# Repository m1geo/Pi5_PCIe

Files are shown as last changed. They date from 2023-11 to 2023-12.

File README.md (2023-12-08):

# Pi5 PCIe & M2 NVMe
A crude reverse engineering of the Raspberry Pi 5's FPC PCIe connector &amp; potential breakout board.

OFFICIAL RASPBERRY PI PCIE DOCOUMENTATION CAN BE FOUND HERE: https://datasheets.raspberrypi.com/pcie/pcie-connector-standard.pdf

In this bare-bones project I document a working PCIe pinout talk through my hardware tinkering to get the Raspberry Pi 5's PCIe connected to something. I had only seen Raspberry Pi's boards with their RP2040 and lots of parts on board. My professional experience with PCIe was that it either just goes or it really doesn't. I decided to try and make it do something for no reason other than the technical challenge.

To see what I did, check out my walkthrough of the process on YouTube: [Raspberry Pi 5 - Unofficial PCIe Success - Hacking the Pi5's PCIe into life](https://youtu.be/G5VOzO_ERTM).

**Note: This project is a reverse engineering - Please wait for/use the [official Raspberry Pi PCIe documentation](https://datasheets.raspberrypi.com/pcie/pcie-connector-standard.pdf) when using the PCIe FPC**

## Pi5 PCIe Breakout Board

The board is a quick test board. It could definitely be improved :)

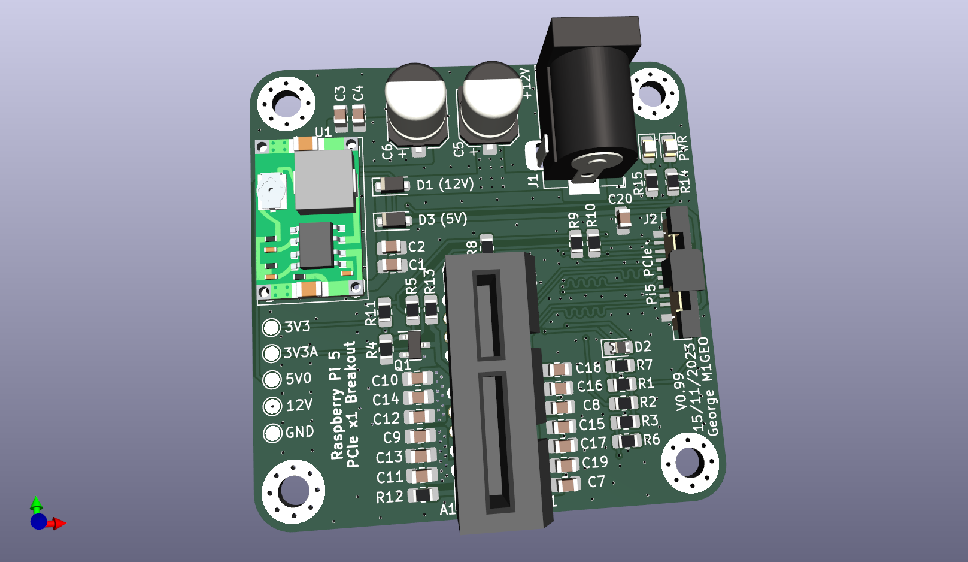
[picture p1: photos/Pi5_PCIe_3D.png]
3D Model of PCIe board


## Pi5 M.2 NVMe Breakout Board

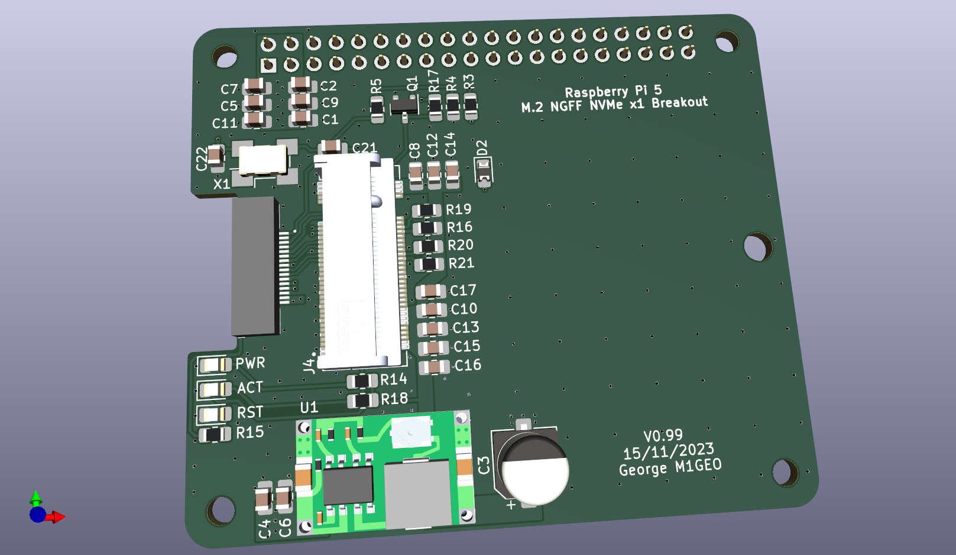
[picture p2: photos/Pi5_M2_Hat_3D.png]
3D Model of M.2 NVMe board


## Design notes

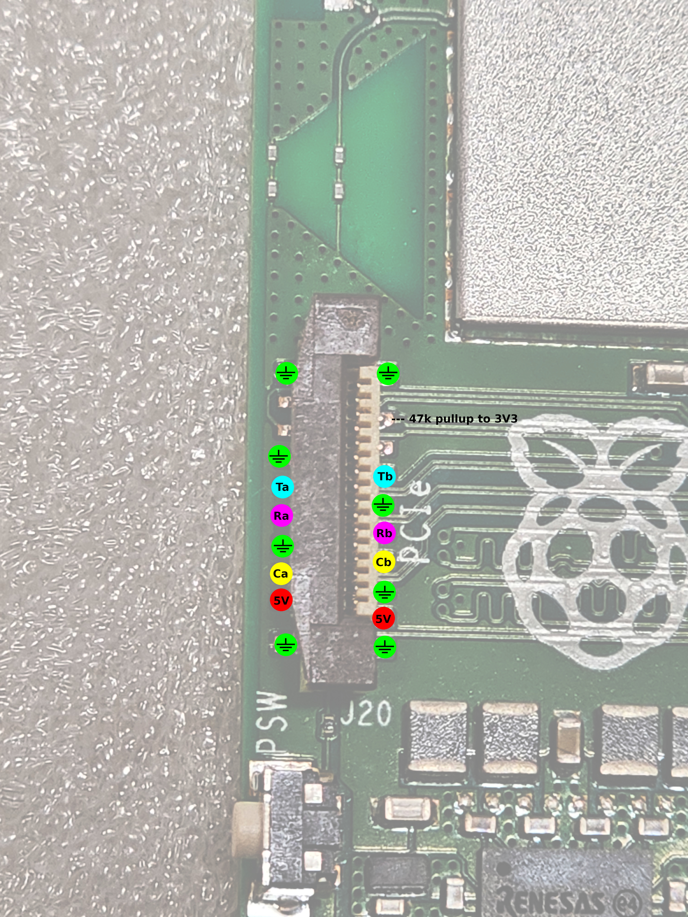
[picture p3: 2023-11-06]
photos/pinout_m1geo.jpg

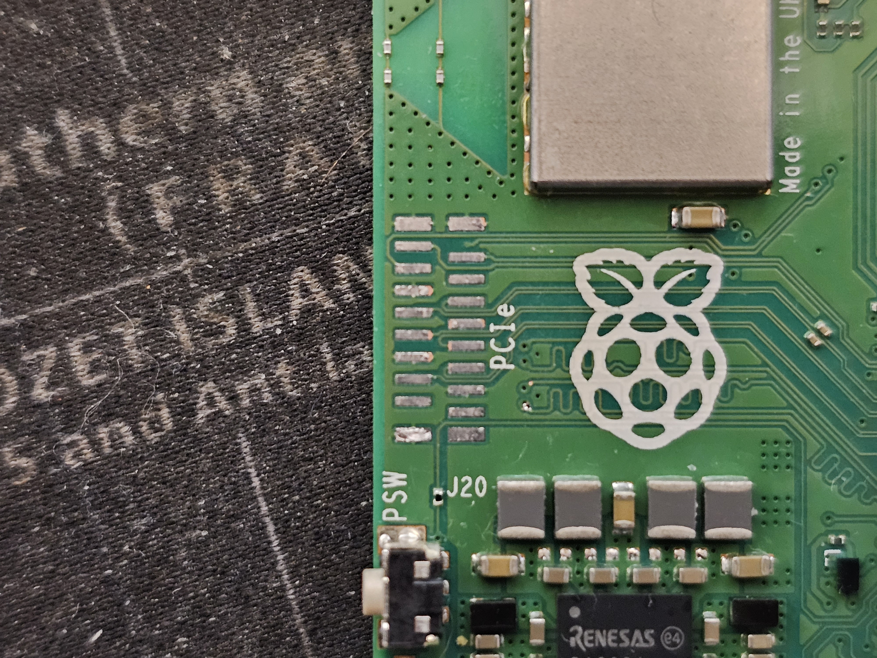
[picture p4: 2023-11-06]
photos/pinout_m1geo2.jpg

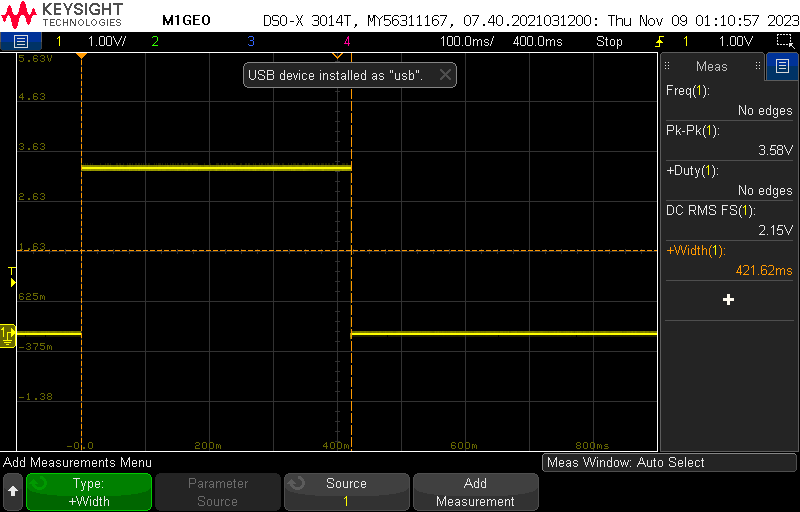
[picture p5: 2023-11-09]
photos/scope_1_pcie_pin1_highpulse.png

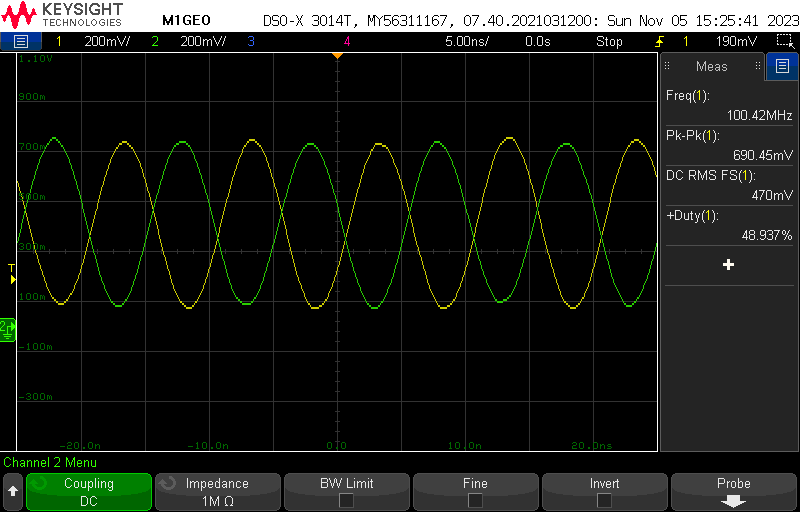
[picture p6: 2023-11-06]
photos/scope_0_pcie_refclk.png

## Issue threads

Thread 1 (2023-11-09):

I2C

trejan, 2023-11-09:
I suspect P3+P4 are I2C and used to communicate with the RP2040 seen on the prototype M.2 HAT. The BCM2712 has two pins muxed to the I2C peripheral and they're named PCIE_SCL/SDA. It isn't the RP1 either as that has a separate I2C bus.

These two pins are configured with the weak internal pulldown enabled and always read as low. The M.2 HAT presumably has the missing I2C pullup resistors.

```
114: a1    pd | lo // PCIE_SDA/GPIO14 = SPI_S_MOSI_OR_BSC_S_SDA
115: a1    pd | lo // PCIE_SCL/GPIO15 = SPI_S_SCK_OR_BSC_S_SCL
```

Should be easy enough to confirm by running _pinctrl_ before & after pulling the pins high.

m1geo, 2023-11-09:
Thanks for this. I'll add provision for this on the board. That's really useful knowledge. I'm also pretty sure that P1 is RST and P2 is CLKREQ (based on probing around with the scope some more). Means there is likely no presence detect (or some magic the RP2040 is doing over I2C with the driver?).

trejan, 2023-11-09:
I expect autodetection would be via I2C like the Poe HATs. The prototype M.2 HAT has a fan connector and current sensing so that'll be via I2C as well if it ends up in the release board. I don't know how much of this is implemented in the public firmware though.

Adding a couple pullup resistors might make it show some activity during startup.

m1geo, 2023-11-09:
Will give that a shot. I'm just looking at the kernel & DT overlay source on the Pi5 GitHub. See if I can work out a way to tell SCL vs SDA when there's no data/clock on the bus.

trejan, 2023-11-09:
Pull up only 1 and see what changes in pinctrl?

m1geo, 2023-11-09:
Using [pinctrl](https://github.com/raspberrypi/utils/tree/master/pinctrl) as suggested by @trejan the following can be observed:

```
$ diff idle.txt p3_high.txt
< 114: a1    pd | lo // PCIE_SDA/GPIO14 = SPI_S_MOSI_OR_BSC_S_SDA
> 114: a1    pd | hi // PCIE_SDA/GPIO14 = SPI_S_MOSI_OR_BSC_S_SDA
```

```
$ diff idle.txt p4_high.txt
< 28: no    pd | lo // PCIE_RP1_WAKE/GPIO28 = none
> 28: no    pd | hi // PCIE_RP1_WAKE/GPIO28 = none
< 115: a1    pd | lo // PCIE_SCL/GPIO15 = SPI_S_SCK_OR_BSC_S_SCL
> 115: a1    pd | hi // PCIE_SCL/GPIO15 = SPI_S_SCK_OR_BSC_S_SCL
```

Interesting that the PCIE_WAKE signal appears to be trigged with the clock being high. Taking this literally, a low BSC_S_SCL/GPIO15 indicates the PCIE_nWAKE request, too? Perhaps the signalling is to use the I2C clock stretching condition to signal a wake?

Couldn't get any life out of P1 and P2. Grounding P2 resulted in no difference from _pinctrl_. I was hoping it may have triggered `RP1_PCIE_CLKREQ_N` (as below) but nothing. Most likely this is for the RP1 chip as RP1 is in the name.

> 36: no    pd | lo // RP1_PCIE_CLKREQ_N/GPIO36 = none

Closing ticket. I2C pins identified. Thanks for the help @trejan!

m1geo, 2023-12-08:
Looking at the [official Pi5 PCIe documentation](https://datasheets.raspberrypi.com/pcie/pcie-connector-standard.pdf),

P4=PCIE_SCL and WAKE is correct.
P3=PCIE_SDA also appears to serve as a PWR_EN signal.

Closed 2023-11-09.

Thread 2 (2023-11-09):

PCIe Lane inter-pair reversal

m1geo, 2023-11-09:
The prototype M.2 HAT doesn't appear to have crossed PCIE_RX0P/N pairs, so I suspect I have them around the wrong way. It works on hardware both ways, so at least one end autodetects. Thus, can't rely on the "working" to be the indicator, and now using the PCB traces to inform.

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
[_AltText:_ Quick drawing showing the RX pair lanes are swapped on the Pi5 connector, confirming there is no twist on the M.2 hat]

Closed 2023-11-09.

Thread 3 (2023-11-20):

help wanted: what is the purpose of optional block?

ubopod, 2023-11-20:
I was wondering what is the purpose of this optional block (oscillator):

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

I guess it would be possible to get full power via FPC connector and connection to Raspberry Pi header 5v is optional?

mfolejewski, 2023-11-22:
that's SUSCLK (32kHz)

"SUSCLK is a 32 kHz clock useful for card power-saving but not required in practice"

https://hackaday.com/2022/11/03/m-2-for-hackers-connectors/

m1geo, 2023-11-23:
Correct. It is to allow peripheral devices to operate from a slow, low power clock in order to do things like assert PCIE_WAKE#. Useful for things like wake-on-LAN.

Closed 2023-11-23.

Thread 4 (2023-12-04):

Hat ID EEPROM

mariusmotea, 2023-12-04:
Hi,

I notice you connect the i2c pins to SMDAT and SMCLK but i think most likely these must be connected to an i2c eeprom chip.

https://hackaday.io/project/167888-not-quite-useless-raspberry-pi-replacement/log/170018-raspberry-pi-hat-id-eeprom-details

https://github.com/raspberrypi/hats

```
A board can only be called a HAT if:

It conforms to the basic add-on board requirements
It has a valid ID EEPROM (including vendor info, GPIO map and valid device tree information).
```

m1geo, 2023-12-07:
The HAT ID EEPROM (including vendor info, GPIO map and valid device tree information) is connected to [GPIO1 pin28](https://pinout.xyz/pinout/pin28_gpio1/) and [GPIO0 pin27](https://pinout.xyz/pinout/pin27_gpio0/).

The PCIe_SMDAT and PCIe_SMCLK come via the 16pin FPC cable. they are different I2C controllers. They're likely used for [IPMI based activities](https://en.wikipedia.org/wiki/Intelligent_Platform_Management_Interface) and [SMBus](https://en.wikipedia.org/wiki/System_Management_Bus) and side-channel data.

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

**TLDR: There are many different I2C controllers on the Pi. We're talking about different ones. Hope that helps.**

m1geo, 2023-12-09:
No, I didn't, but the 16p header isn't for the HAT EEPROM. The official spec (see main readme) doesn't list the I2C, so I guess there's no offical support. The HAT EEPROM will need to connect to the GPIO header EEPROM pins.

mariusmotea, 2023-12-09:
Pineberry has released two pcie adapters one using the 40 pin header and one using only the PCIe 16 pin connector. I looked at the pics on the one that use only the PCIe connector and the i2c pins go to two components, one looks to be the eeprom chip and the second is an i2c current measurement.

From specs:

 - Dedicated I2C EEPROM Memory: Fully compatible with HAT ID for advanced functionality and configuration.
 - Advanced Power Monitoring and Diagnostics: Continuous, real-time monitoring and diagnostic system for voltage, current, and power parameters via an I2C interface.

mikegapinski, 2023-12-10:
I can't say too much about this yet but we are planning on using the I2C on the HatDrive Bottom that does not use the GPIO directly. The current monitoring feature is very important to us and we found a decently elegant solution that will make it work without any hardware changes on the boards that are currently shipping out.

We do however ship both the boards in the first batch with an empty EEPROM since the payload for auto detection is not yet public, we'll release an update script that'll make it work as soon as we know the details. Right now you need to use the PCIE_PROBE bootloader config flag to enable booting from NVMe. That is what the HAT+ spec will bring.

I don't understand why:
1. PCIe enumeration is not happening by default if there is no SD present. What is the point of changing the config to enable this?
2. I2C on the 16pin FPC evaporated from the final spec, it is connected/present in the SOC but not supported in the firmware. HABs or PIPs (or whatever you decide to call them) are better than standard NVMe HATs that go over the GPIO in so many ways. We also see more demand for them, and the upcoming competition (Pimoroni etc) also went with this approach. I think that they'll add ID detection for those type of designs at some point, it just makes sense.

If "PCIe_SMDAT" and "PCIe_SMCLK" are indeed GPIO pins that are coming from the 2712 directly there should be a way to make them appear as a I2C device with a overlay / device tree config change. I'd love to have the time to play around with the kernel more but we are swamped with orders. I'll get this figured out one day I hope.

m1geo, 2023-12-10:
See #1 for I2C pinout on the FPC 16-pin connector.

Closed 2023-12-07.

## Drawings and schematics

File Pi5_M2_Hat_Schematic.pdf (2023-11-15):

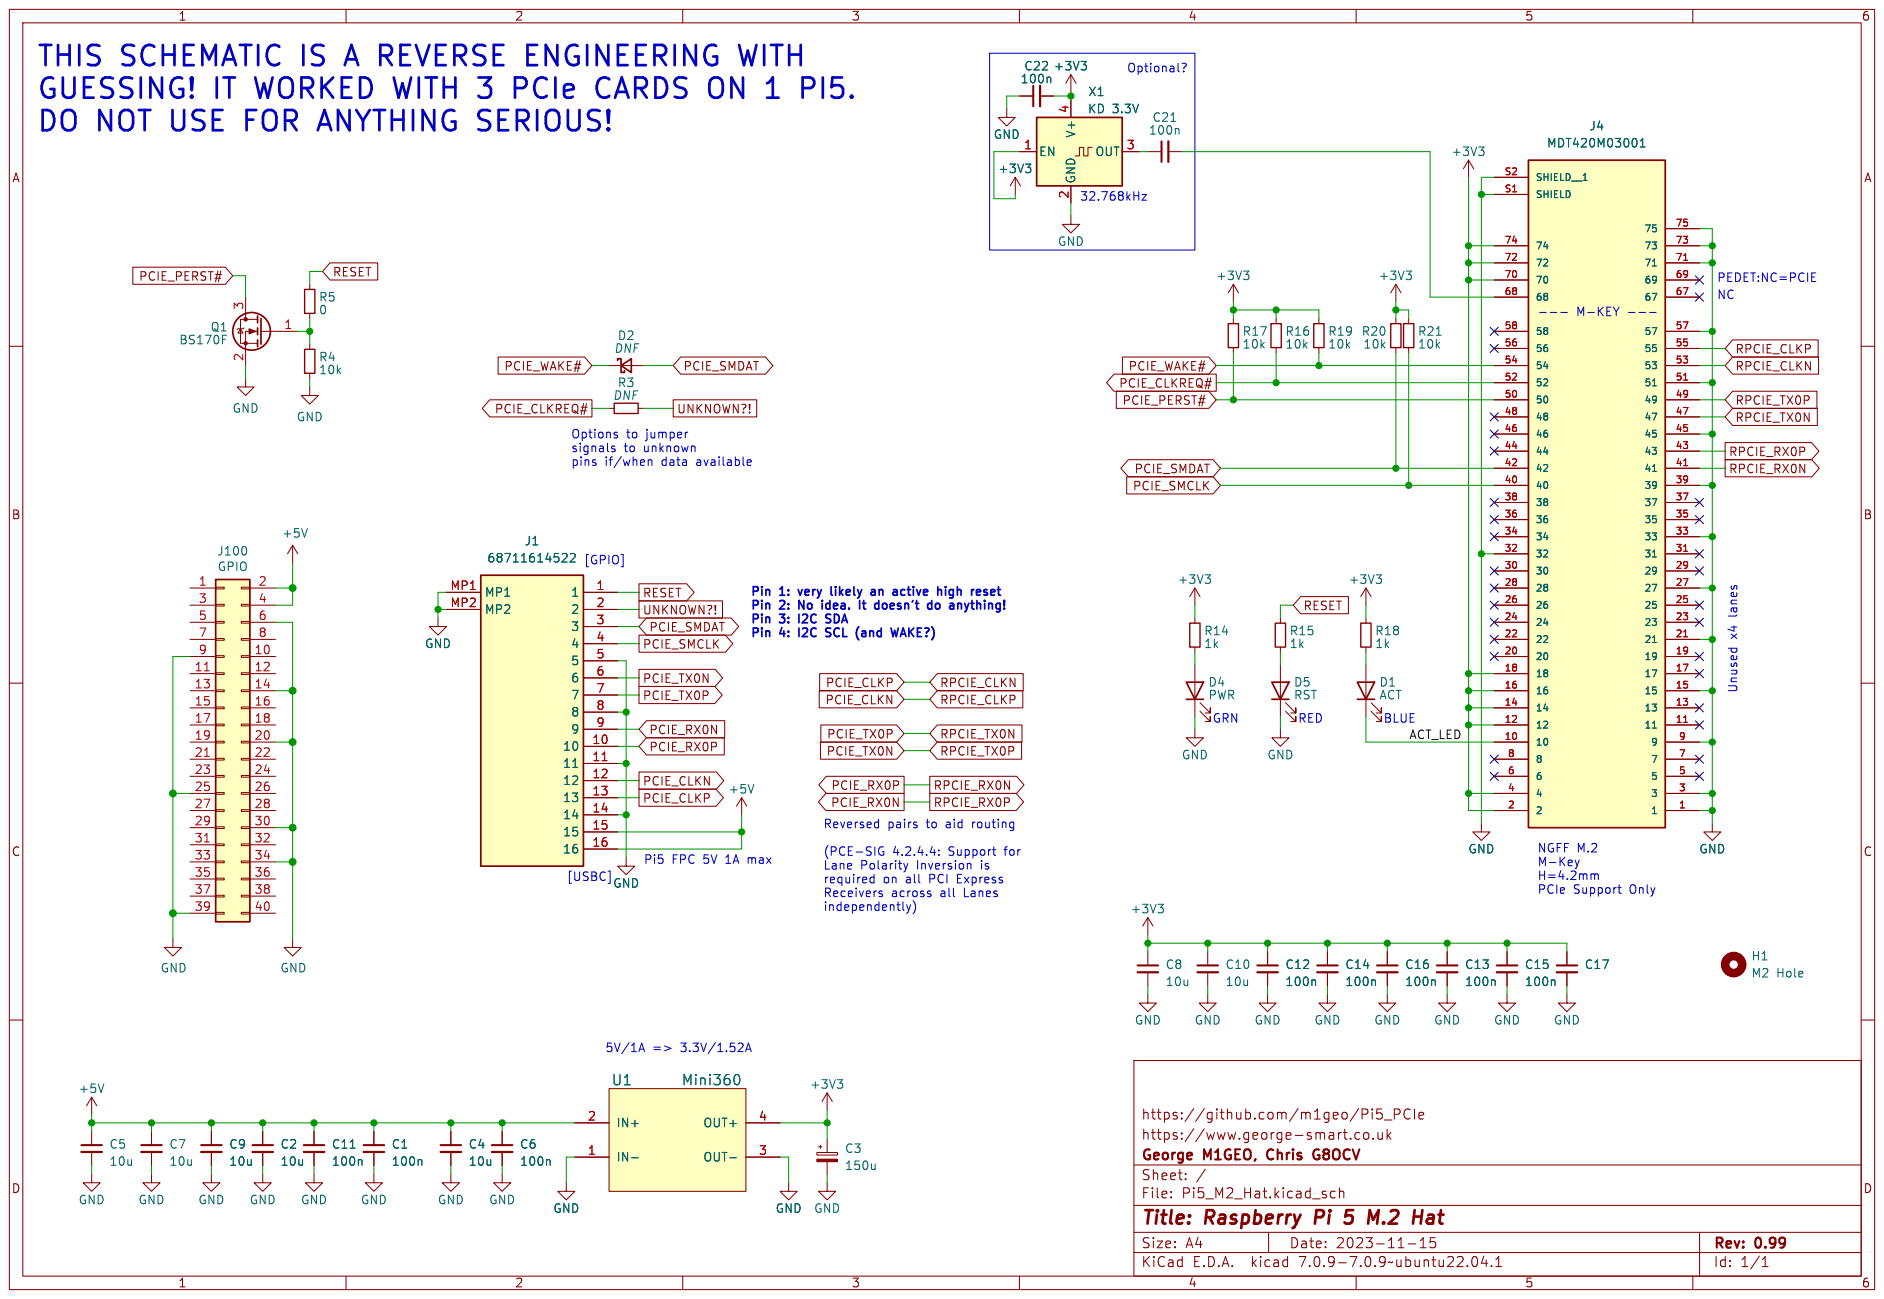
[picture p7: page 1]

Optional? Reversed pairs to aid routing

GUESSING! IT WORKED WITH 3 PCIe CARDS ON 1 PI5.

32.768kHz Pin 1: very likely an active high reset Pin 2: No idea. It doesn't do anything! Pin 3: I2C SDA

https://github.com/m1geo/Pi5_PCIe
https://www.george-smart.co.uk

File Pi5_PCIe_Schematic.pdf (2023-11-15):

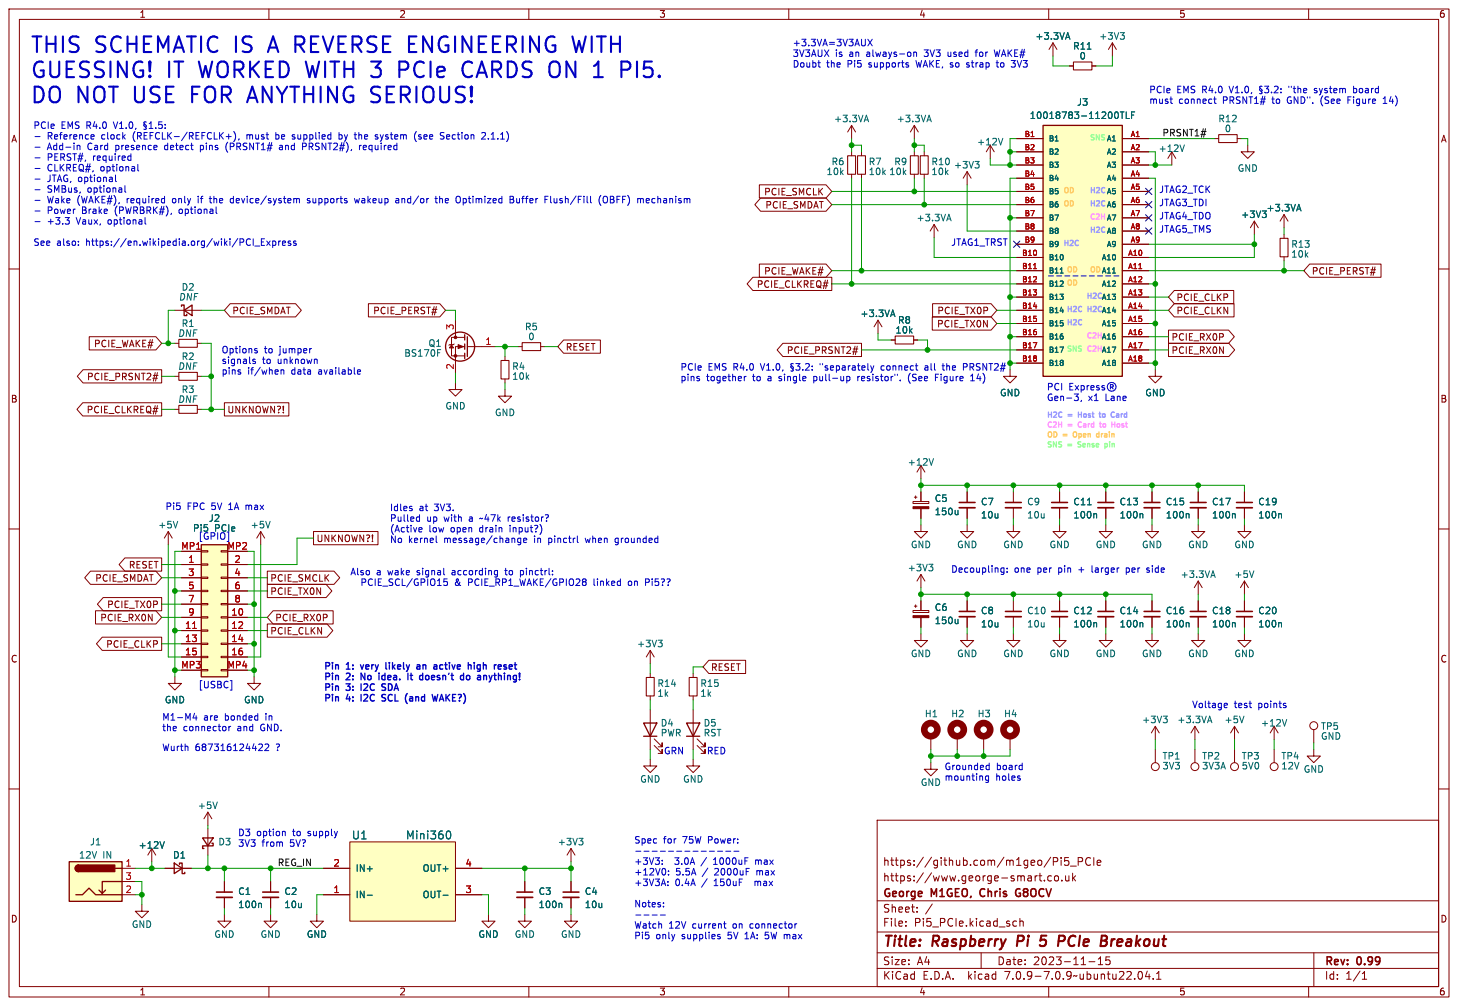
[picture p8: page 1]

SNS THIS SCHEMATIC IS A REVERSE ENGINEERING WITH
GUESSING! IT WORKED WITH 3 PCIe CARDS ON 1 PI5.
DO NOT USE FOR ANYTHING SERIOUS!

C2H = Card to Host H2C = Host to Card Options to jumper
signals to unknown

Idles at 3V3. Pulled up with a ~47k resistor?

Pin 4: I2C SCL (and WAKE?)

https://github.com/m1geo/Pi5_PCIe GND

https://www.george-smart.co.uk

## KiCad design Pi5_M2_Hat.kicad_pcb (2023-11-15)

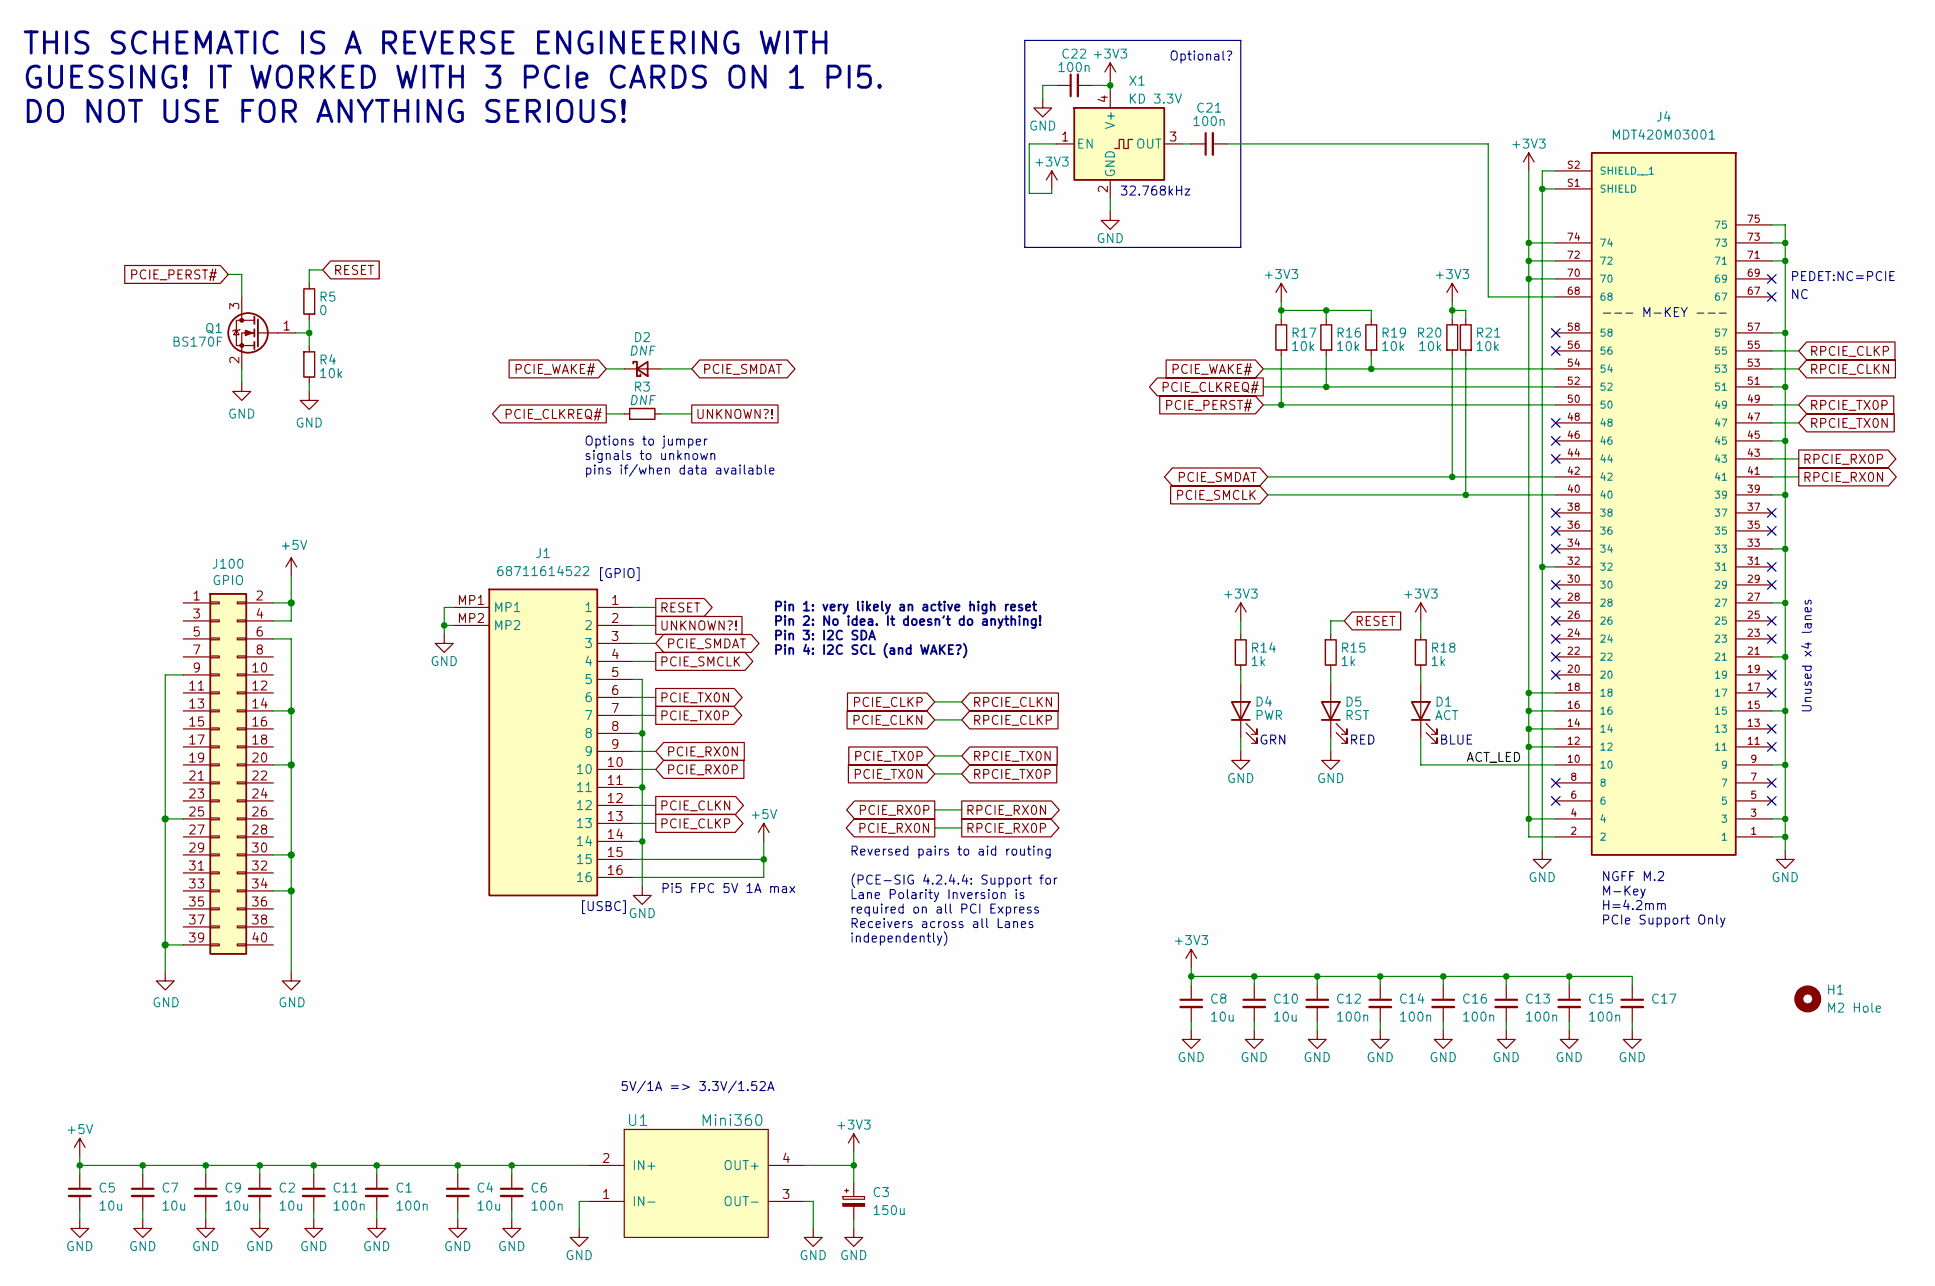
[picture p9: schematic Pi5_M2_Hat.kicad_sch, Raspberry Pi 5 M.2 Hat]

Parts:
C1, C6, C11, C12, C13, C14, C15, C16, C17, C21, C22: 100n; C_0805_2012Metric_Pad1.18x1.45mm_HandSolder
C2, C4, C5, C7, C8, C9, C10: 10u; C_0805_2012Metric_Pad1.18x1.45mm_HandSolder
C3: 150u; CP_Elec_6.3x7.7; LCSC C3032176
D1: ACT; LED_0805_2012Metric_Pad1.15x1.40mm_HandSolder
D2: DNF; D_0805_2012Metric_Pad1.15x1.40mm_HandSolder; LCSC C23848
D4: PWR; LED_0805_2012Metric_Pad1.15x1.40mm_HandSolder
D5: RST; LED_0805_2012Metric_Pad1.15x1.40mm_HandSolder
H1: M2 Hole; MountingHole_3.2mm_M3
J1: 68711614522; Manufacturer_Part_Number 68711614522; Mouser Part Number 710-68711614522
J4: MDT420M03001; AMPHENOL_MDT420M03001
J100: GPIO; PinSocket_2x20_P2.54mm_Vertical
Q1: BS170F; SOT-23
R3: DNF; R_0805_2012Metric_Pad1.20x1.40mm_HandSolder
R4, R16, R17, R19, R20, R21: 10k; R_0805_2012Metric_Pad1.20x1.40mm_HandSolder
R5: 0; R_0805_2012Metric_Pad1.20x1.40mm_HandSolder
R14, R15, R18: 1k; R_0805_2012Metric_Pad1.20x1.40mm_HandSolder
U1: Mini360; Mini360_step-down
X1: KD 3.3V; Oscillator_SMD_Fordahl_DFAS15-4Pin_5.0x3.2mm_HandSoldering

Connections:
+3V3: C3.1, C8.1, C10.1, C12.1, C13.1, C14.1, C15.1, C16.1, C17.1, C22.2, J4.2, J4.4, J4.12, J4.14, J4.16, J4.18, J4.70, J4.72, J4.74, R14.1, R16.2, R17.2, R18.1, R19.2, R20.2, R21.2, U1.4 (OUT+), X1.1 (EN), X1.4 (V+)
+5V: C1.1, C2.1, C4.1, C5.1, C6.1, C7.1, C9.1, C11.1, J1.15, J1.16, J100.2, J100.4, U1.2 (IN+)
/ACT_LED: D1.1 (K), J4.10
GND: C1.2, C2.2, C3.2, C4.2, C5.2, C6.2, C7.2, C8.2, C9.2, C10.2, C11.2, C12.2, C13.2, C14.2, C15.2, C16.2, C17.2, C22.1, D4.1 (K), D5.1 (K), J1.5, J1.8, J1.11, J1.14, J1.MP1, J1.MP2, J4.1, J4.3, J4.9, J4.15, J4.21, J4.27, J4.32, J4.33, J4.39, J4.45, J4.51, J4.57, J4.71, J4.73, J4.75, J4.S1 (SHIELD), J4.S2 (SHIELD__1), J100.6, J100.9, J100.14, J100.20, J100.25, J100.30, J100.34, J100.39, Q1.2 (S), R4.2, U1.1 (IN-), U1.3 (OUT-), X1.2 (GND)
unnamed: C21.2, J4.68
unnamed: D1.2 (A), R18.2
unnamed: D4.2 (A), R14.2
unnamed: D5.2 (A), R15.2
unnamed: Q1.1 (G), R4.1, R5.1
unnamed: C21.1, X1.3 (OUT)
PCIE_CLKN: J1.12, J4.55
PCIE_CLKP: J1.13, J4.53
PCIE_CLKREQ#: J4.52, R3.1, R16.1
PCIE_PERST#: J4.50, Q1.3 (D), R17.1
PCIE_RX0N: J1.9, J4.43
PCIE_RX0P: J1.10, J4.41
PCIE_SMCLK: J1.4, J4.40, R21.1
PCIE_SMDAT: D2.2 (A), J1.3, J4.42, R20.1
PCIE_TX0N: J1.6, J4.49
PCIE_TX0P: J1.7, J4.47
PCIE_WAKE#: D2.1 (K), J4.54, R19.1
RESET: J1.1, R5.2, R15.1
UNKNOWN?!: J1.2, R3.2

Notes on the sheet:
PEDET:NC=PCIE
BLUE
RED
THIS SCHEMATIC IS A REVERSE ENGINEERING WITH GUESSING! IT WORKED WITH 3 PCIe CARDS ON 1 PI5. DO NOT USE FOR ANYTHING SERIOUS!
[USBC]
--- M-KEY ---
Pin 1: very likely an active high reset Pin 2: No idea. It doesn't do anything! Pin 3: I2C SDA Pin 4: I2C SCL (and WAKE?)
32.768kHz
Options to jumper signals to unknown pins if/when data available
Optional?
Unused x4 lanes
Pi5 FPC 5V 1A max
Reversed pairs to aid routing (PCE-SIG 4.2.4.4: Support for Lane Polarity Inversion is required on all PCI Express Receivers across all Lanes independently)
NGFF M.2 M-Key H=4.2mm PCIe Support Only
[GPIO]
GRN
5V/1A => 3.3V/1.52A

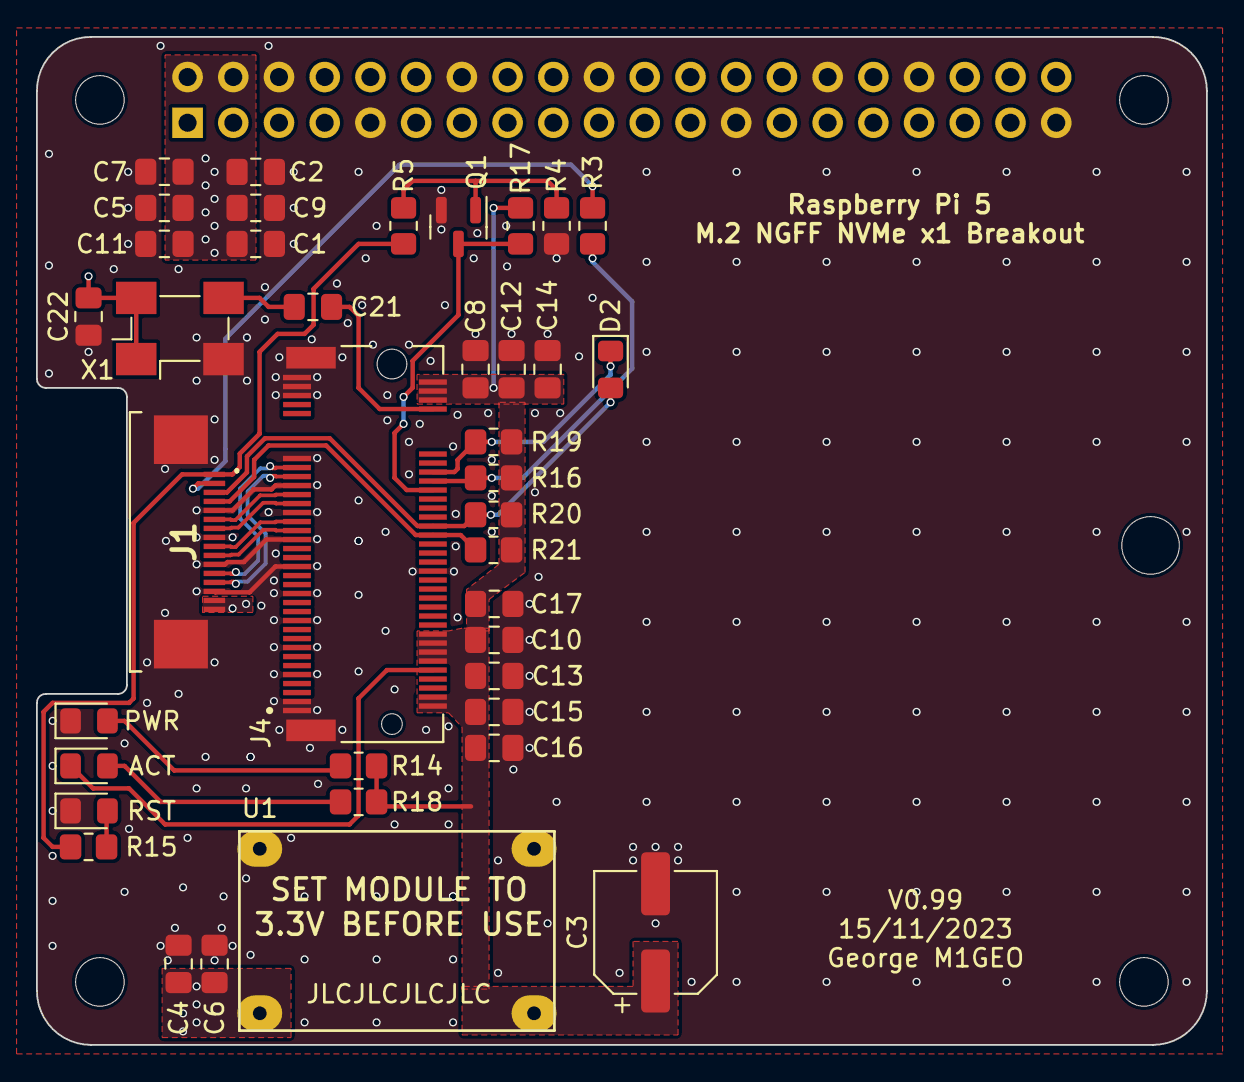
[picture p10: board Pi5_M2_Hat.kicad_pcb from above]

Board: 4 copper layers, 65.0 x 56.0 mm, 45 parts (1 on the bottom side), 23 nets.

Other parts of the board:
MH1, MH2, MH3, MH4: MountingHole_2.7mm_M2.5

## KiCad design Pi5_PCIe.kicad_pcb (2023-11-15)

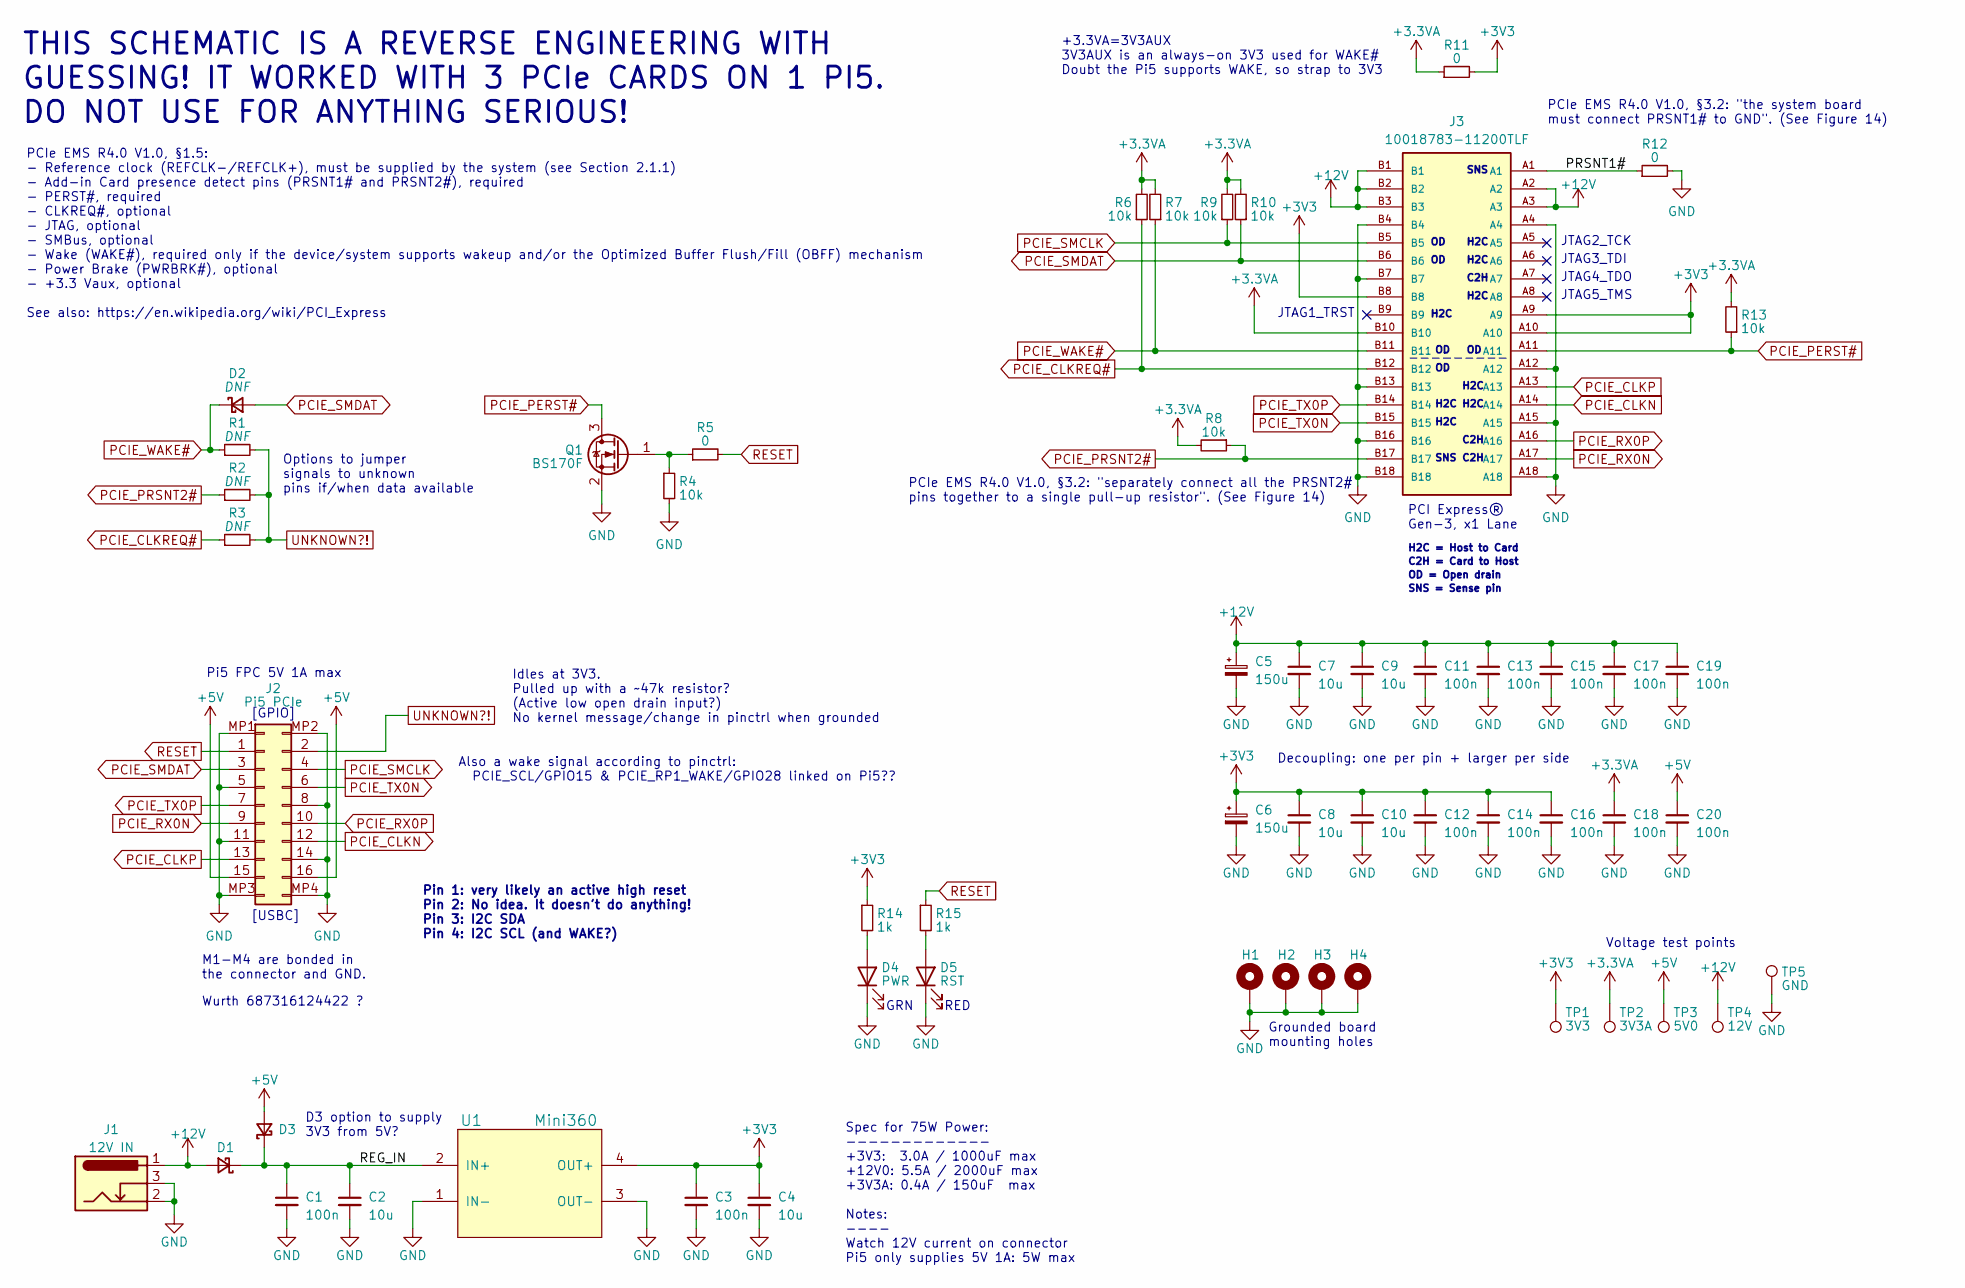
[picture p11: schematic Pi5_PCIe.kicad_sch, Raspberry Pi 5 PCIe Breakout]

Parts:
C1, C3, C11, C12, C13, C14, C15, C16, C17, C18, C19, C20: 100n; C_0805_2012Metric_Pad1.18x1.45mm_HandSolder
C2, C4, C7, C8, C9, C10: 10u; C_0805_2012Metric_Pad1.18x1.45mm_HandSolder
C5, C6: 150u; CP_Elec_6.3x7.7; LCSC C3032176
D1: (12V); D_SOD-123F; LCSC C23848
D2: DNF; D_0805_2012Metric_Pad1.15x1.40mm_HandSolder; LCSC C23848
D3: (5V); D_SOD-123F; LCSC C23848
D4: PWR; LED_0805_2012Metric_Pad1.15x1.40mm_HandSolder
D5: RST; LED_0805_2012Metric_Pad1.15x1.40mm_HandSolder
H1, H2, H3, H4: MountingHole_Pad; MountingHole_3.2mm_M3_Pad_Via
J1: 12V IN; BarrelJack_Horizontal; LCSC C319099
J2: Pi5 PCIe; 687316124422; MPN Wurth 687316124422
J3: 10018783-11200TLF; AMPHENOL_10018783-11200TLF; PARTREV Z
Q1: BS170F; SOT-23
R1, R2, R3: DNF; R_0805_2012Metric_Pad1.20x1.40mm_HandSolder
R4, R6, R7, R8, R9, R10, R13: 10k; R_0805_2012Metric_Pad1.20x1.40mm_HandSolder
R5, R11, R12: 0; R_0805_2012Metric_Pad1.20x1.40mm_HandSolder
R14, R15: 1k; R_0805_2012Metric_Pad1.20x1.40mm_HandSolder
TP1: 3V3; TestPoint_Pad_D1.5mm
TP2: 3V3A; TestPoint_Pad_D1.5mm
TP3: 5V0; TestPoint_Pad_D1.5mm
TP4: 12V; TestPoint_Pad_D1.5mm
TP5: GND; TestPoint_Pad_D1.5mm
U1: Mini360; Mini360_step-down

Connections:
+3.3VA: C18.1, J3.B10, R6.2, R7.2, R8.2, R9.2, R10.2, R11.1, R13.2, TP2.1
+3V3: C3.1, C4.1, C6.1, C8.1, C10.1, C12.1, C14.1, C16.1, J3.A9, J3.A10, J3.B8, R11.2, R14.1, TP1.1, U1.4 (OUT+)
+5V: C20.1, D3.2 (A), J2.15 (Pin_17), J2.16 (Pin_18), TP3.1
+12V: C5.1, C7.1, C9.1, C11.1, C13.1, C15.1, C17.1, C19.1, D1.2 (A), J1.1, J3.A2, J3.A3, J3.B1, J3.B2, J3.B3, TP4.1
/PRSNT1#: J3.A1, R12.1
/REG_IN: C1.1, C2.1, D1.1 (K), D3.1 (K), U1.2 (IN+)
GND: C1.2, C2.2, C3.2, C4.2, C5.2, C6.2, C7.2, C8.2, C9.2, C10.2, C11.2, C12.2, C13.2, C14.2, C15.2, C16.2, C17.2, C18.2, C19.2, C20.2, D4.1 (K), D5.1 (K), H1.1, H2.1, H3.1, H4.1, J1.2, J1.3, J2.5 (Pin_7), J2.8 (Pin_10), J2.11 (Pin_13), J2.14 (Pin_16), J2.MP1, J2.MP2, J2.MP3, J2.MP4, J3.A4, J3.A12, J3.A15, J3.A18, J3.B4, J3.B7, J3.B13, J3.B16, J3.B18, Q1.2 (S), R4.2, R12.2, TP5.1, U1.1 (IN-), U1.3 (OUT-)
unnamed: D4.2 (A), R14.2
unnamed: D5.2 (A), R15.2
unnamed: Q1.1 (G), R4.1, R5.1
PCIE_CLKN: J2.12 (Pin_14), J3.A14
PCIE_CLKP: J2.13 (Pin_15), J3.A13
PCIE_CLKREQ#: J3.B12, R3.1, R6.1
PCIE_PERST#: J3.A11, Q1.3 (D), R13.1
PCIE_PRSNT2#: J3.B17, R2.1, R8.1
PCIE_RX0N: J2.9 (Pin_11), J3.A17
PCIE_RX0P: J2.10 (Pin_12), J3.A16
PCIE_SMCLK: J2.4 (Pin_6), J3.B5, R9.1
PCIE_SMDAT: D2.2 (A), J2.3 (Pin_5), J3.B6, R10.1
PCIE_TX0N: J2.6 (Pin_8), J3.B15
PCIE_TX0P: J2.7 (Pin_9), J3.B14
PCIE_WAKE#: D2.1 (K), J3.B11, R1.1, R7.1
RESET: J2.1 (Pin_3), R5.2, R15.1
UNKNOWN?!: J2.2 (Pin_4), R1.2, R2.2, R3.2

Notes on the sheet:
JTAG3_TDI
C2H
RED
PCIe EMS R4.0 V1.0, §3.2: "the system board must connect PRSNT1# to GND". (See Figure 14)
H2C = Host to Card
C2H = Card to Host
Decoupling: one per pin + larger per side
JTAG4_TDO
---------
JTAG1_TRST
THIS SCHEMATIC IS A REVERSE ENGINEERING WITH GUESSING! IT WORKED WITH 3 PCIe CARDS ON 1 PI5. DO NOT USE FOR ANYTHING SERIOUS!
[USBC]
SNS = Sense pin
Pin 1: very likely an active high reset Pin 2: No idea. It doesn't do anything! Pin 3: I2C SDA Pin 4: I2C SCL (and WAKE?)
SNS
H2C
Voltage test points
+3.3VA=3V3AUX 3V3AUX is an always-on 3V3 used for WAKE# Doubt the Pi5 supports WAKE, so strap to 3V3
JTAG2_TCK
D3 option to supply 3V3 from 5V?
Wurth 687316124422 ?
Options to jumper signals to unknown pins if/when data available
PCIe EMS R4.0 V1.0, §1.5: - Reference clock (REFCLK-/REFCLK+), must be supplied by the system (see Section 2.1.1) - Add-in Card presence detect pins (PRSNT1# and PRSNT2#), required - PERST#, required - CLKREQ#, optional - JTAG, optional - SMBus, optional - Wake (WAKE#), required only if the device/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
PCI Express® Gen-3, x1 Lane
Spec for 75W Power: ------------- +3V3: 3.0A / 1000uF max +12V0: 5.5A / 2000uF max +3V3A: 0.4A / 150uF max Notes: ---- Watch 12V current on connector Pi5 only supplies 5V 1A: 5W max
Also a wake signal according to pinctrl: PCIE_SCL/GPIO15 & PCIE_RP1_WAKE/GPIO28 linked on Pi5??
Pi5 FPC 5V 1A max
Grounded board mounting holes
JTAG5_TMS
M1-M4 are bonded in the connector and GND.
Idles at 3V3. Pulled up with a ~47k resistor? (Active low open drain input?) No kernel message/change in pinctrl when grounded
PCIe EMS R4.0 V1.0, §3.2: "separately connect all the PRSNT2# pins together to a single pull-up resistor". (See Figure 14)
[GPIO]
OD = Open drain
GRN

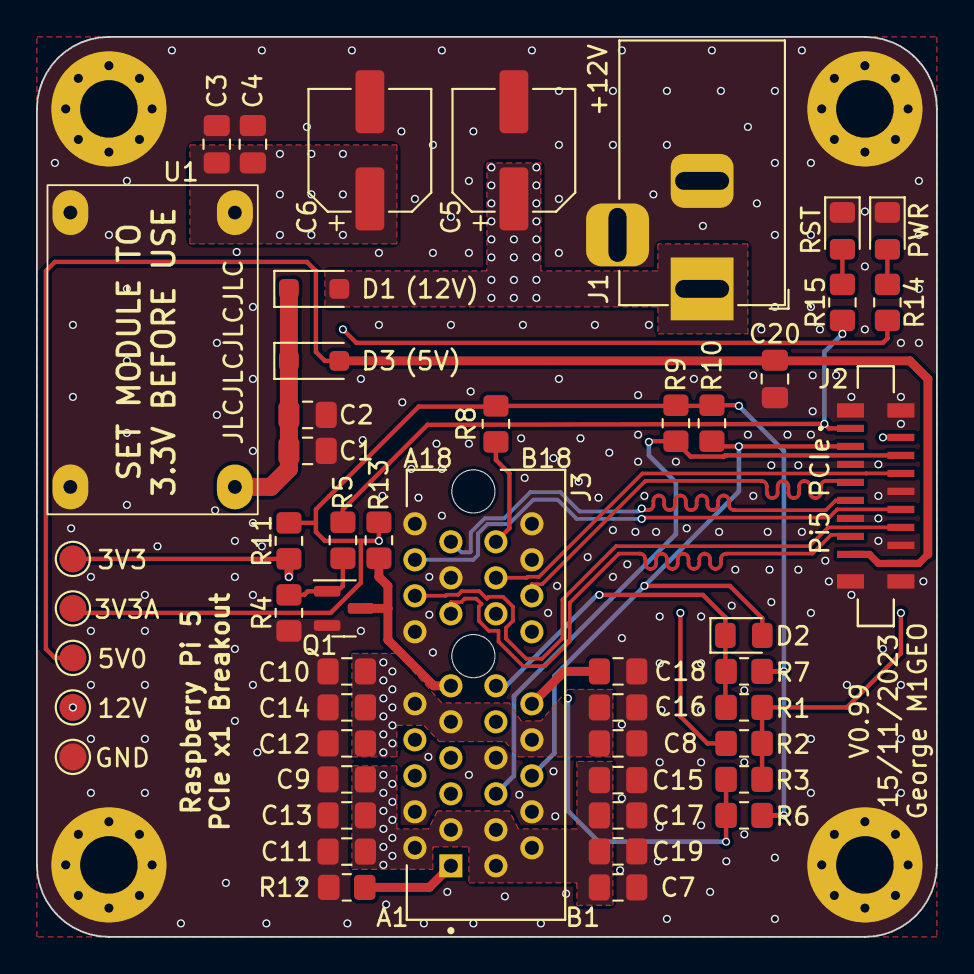
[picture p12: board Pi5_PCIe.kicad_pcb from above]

Board: 4 copper layers, 50.0 x 50.0 mm, 54 parts (0 on the bottom side), 24 nets.

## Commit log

2023-11-06 Added PDF schematic for easier viewing
2023-11-07 Schematic tweaks towards making a test PCB
    [Pi5_PCIe.kicad_sch]
2023-11-09 Added scope print of pin1 toggling high on startup
2023-11-09 Updated schematic based on testing & PCB layout * Used pinctrl to find out what P3 & P4 did, as suggested by @trejan * Reviewed Pi5 layout under connector to see that I had RX(P|N) swapped
    [Pi5_PCIe.kicad_sch]
2023-11-11 Quick test PCIe breakout board
    [Pi5_PCIe.kicad_pcb, Pi5_PCIe.kicad_sch]
2023-11-15 Created Gerbers for board v0.99 & tagged
    [Pi5_M2_Hat.kicad_pcb, Pi5_M2_Hat.kicad_sch, Pi5_PCIe.kicad_pcb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]
